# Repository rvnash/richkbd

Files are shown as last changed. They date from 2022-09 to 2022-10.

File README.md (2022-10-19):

# richkbd 2.0
 
The richkbd keyboard is a 42 key single piece Kaihl Choc Hotswap based keyboard which uses the [RP2040](https://www.raspberrypi.com/products/rp2040/) microcontroller. The layout of the keys is identical to two [Corne keyboards](https://github.com/foostan/crkbd) joined together into one. The halves are placed 21° from horizontal and the top keys are separated by 35mm.

If you wanted to construct your own, take a look at the [Build Guide](doc/buildguide.md).

## Features

- Powered by the [RP2040 Stamp](https://www.solder.party/docs/rp2040-stamp) helper board
- USB-C Card edge connector
- Neopixel LED per key
- OLED Display
- Buttons to reset and enter bootloader mode
- Fairly thin with a bottom plate, PCB board layer, and a top layer to hold the sockets
 
## Software

There is a full QMK software implementation which you can find [here](https://github.com/rvnash/qmk_firmware/tree/rvnash_rp2040/keyboards/rvnash/richkbd). If you don't enjoy working from the source, you can find a released flashable version [here](https://github.com/rvnash/qmk_firmware/releases).

## Photos

Here is a completed keyboard with a random selection of keycaps on.

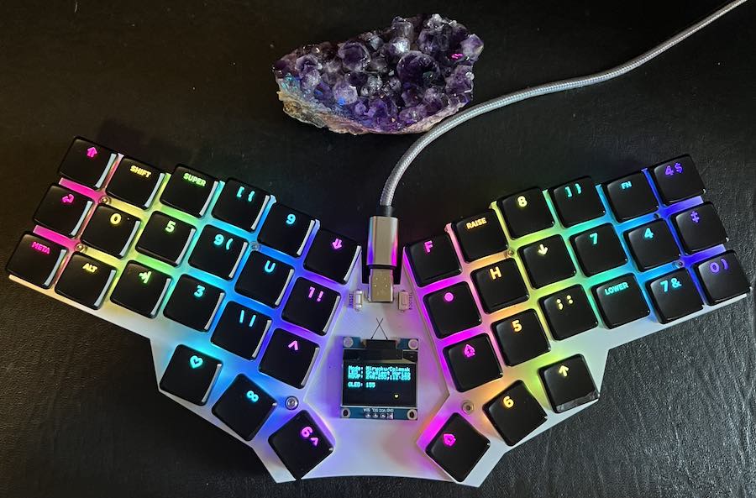
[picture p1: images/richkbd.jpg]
richkbd


Side View

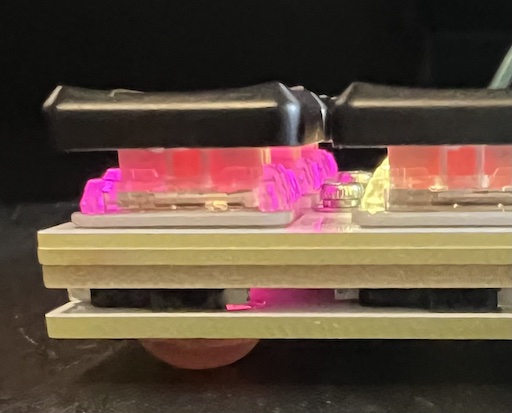
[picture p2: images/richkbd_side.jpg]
richkbd side


The raw PCB

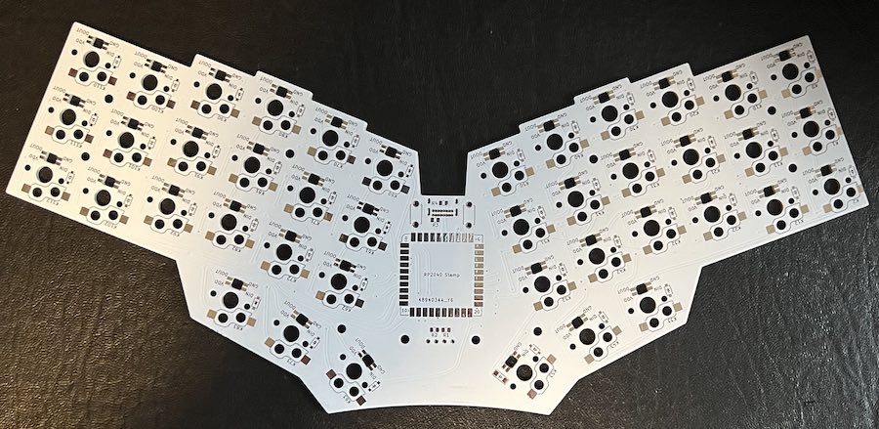
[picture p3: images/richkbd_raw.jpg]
richkbd raw


A soldered PCB

populated

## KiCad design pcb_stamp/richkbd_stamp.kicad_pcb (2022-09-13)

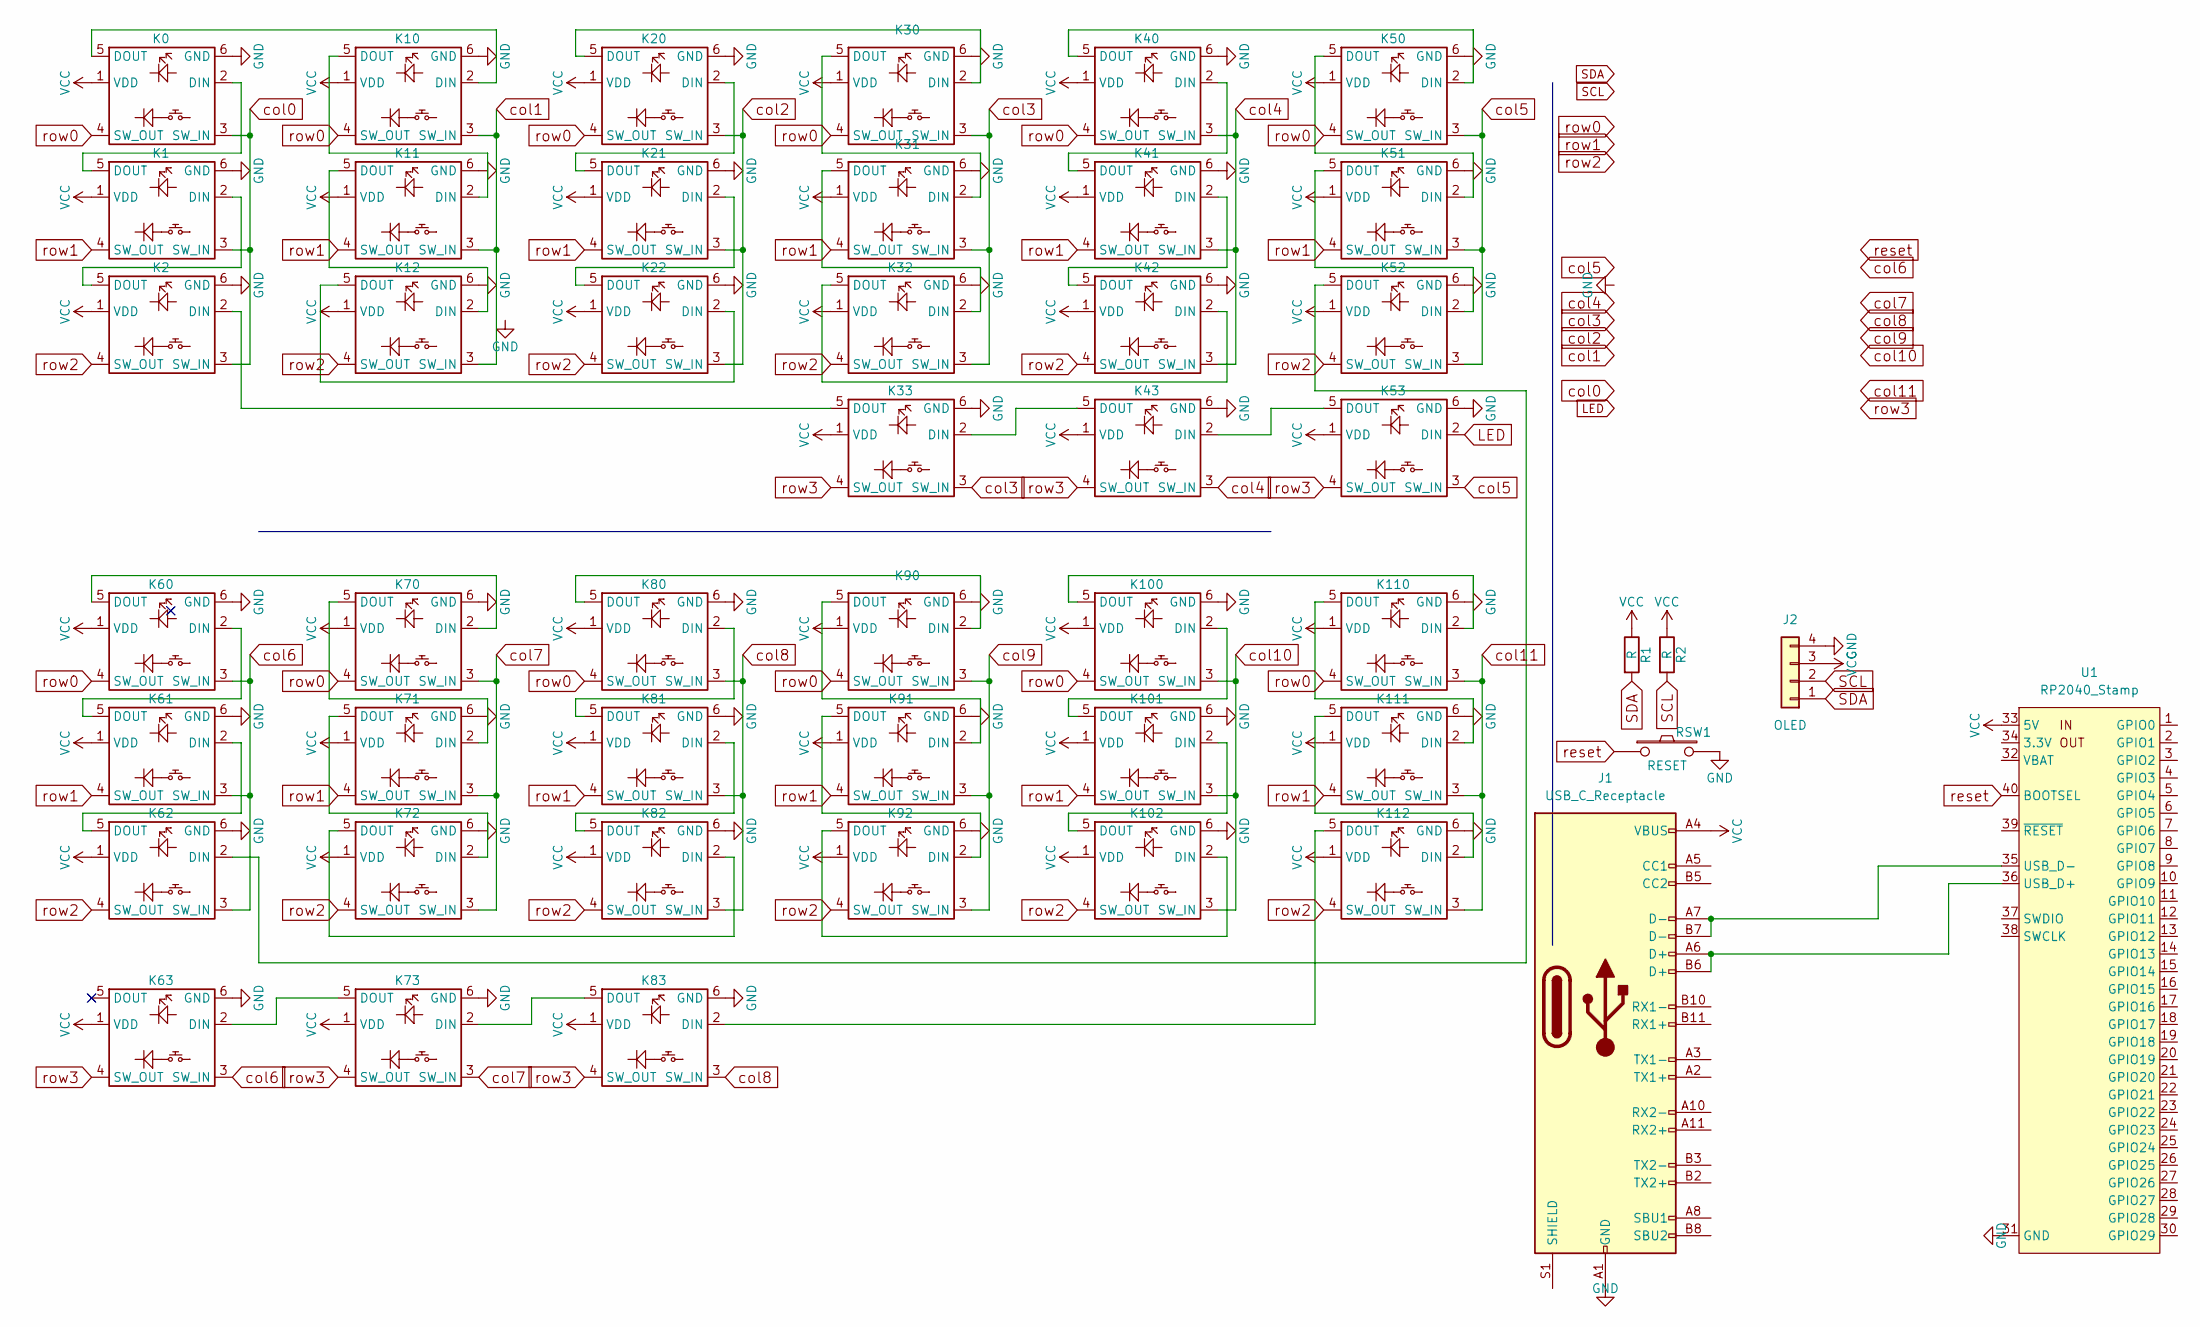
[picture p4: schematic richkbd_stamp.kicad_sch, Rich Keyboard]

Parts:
J1: USB_C_Receptacle
J2: OLED
K0, K1, K2, K10, K11, K12, K20, K21, K22, K30, K31, K32, K33, K40, K41, K42, K43, K50, K51, K52, K53, K60, K61, K62, K63, K70, K71, K72, K73, K80, K81, K82, K83, K90, K91, K92, K100, K101, K102, K110, K111, K112: key-diode-led; key_diode_led
R1, R2: R
RSW1: RESET; ResetSW
U1: RP2040_Stamp; RP2040_Stamp_SMD

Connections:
GND: J1.A1 (GND), J1.A12 (GND), J1.B1 (GND), J1.B12 (GND), J2.4, K0.6 (GND), K1.6 (GND), K2.6 (GND), K10.6 (GND), K11.6 (GND), K12.6 (GND), K20.6 (GND), K21.6 (GND), K22.6 (GND), K30.6 (GND), K31.6 (GND), K32.6 (GND), K33.6 (GND), K40.6 (GND), K41.6 (GND), K42.6 (GND), K43.6 (GND), K50.6 (GND), K51.6 (GND), K52.6 (GND), K53.6 (GND), K60.6 (GND), K61.6 (GND), K62.6 (GND), K63.6 (GND), K70.6 (GND), K71.6 (GND), K72.6 (GND), K73.6 (GND), K80.6 (GND), K81.6 (GND), K82.6 (GND), K83.6 (GND), K90.6 (GND), K91.6 (GND), K92.6 (GND), K100.6 (GND), K101.6 (GND), K102.6 (GND), K110.6 (GND), K111.6 (GND), K112.6 (GND), RSW1.2, U1.31 (GND)
LED: K53.2 (DIN)
unnamed: J1.A6 (D+), J1.B6 (D+), U1.36 (USB_D+)
unnamed: J1.A7 (D-), J1.B7 (D-), U1.35 (USB_D-)
unnamed: K0.2 (DIN), K1.5 (DOUT)
unnamed: K0.5 (DOUT), K10.2 (DIN)
unnamed: K1.2 (DIN), K2.5 (DOUT)
unnamed: K2.2 (DIN), K33.5 (DOUT)
unnamed: K10.5 (DOUT), K11.2 (DIN)
unnamed: K11.5 (DOUT), K12.2 (DIN)
unnamed: K12.5 (DOUT), K22.2 (DIN)
unnamed: K20.2 (DIN), K21.5 (DOUT)
unnamed: K20.5 (DOUT), K30.2 (DIN)
unnamed: K21.2 (DIN), K22.5 (DOUT)
unnamed: K30.5 (DOUT), K31.2 (DIN)
unnamed: K31.5 (DOUT), K32.2 (DIN)
unnamed: K32.5 (DOUT), K42.2 (DIN)
unnamed: K33.2 (DIN), K43.5 (DOUT)
unnamed: K40.2 (DIN), K41.5 (DOUT)
unnamed: K40.5 (DOUT), K50.2 (DIN)
unnamed: K41.2 (DIN), K42.5 (DOUT)
unnamed: K43.2 (DIN), K53.5 (DOUT)
unnamed: K50.5 (DOUT), K51.2 (DIN)
unnamed: K51.5 (DOUT), K52.2 (DIN)
unnamed: K52.5 (DOUT), K62.2 (DIN)
unnamed: K60.2 (DIN), K61.5 (DOUT)
unnamed: K60.5 (DOUT), K70.2 (DIN)
unnamed: K61.2 (DIN), K62.5 (DOUT)
unnamed: K63.2 (DIN), K73.5 (DOUT)
unnamed: K70.5 (DOUT), K71.2 (DIN)
unnamed: K71.5 (DOUT), K72.2 (DIN)
unnamed: K72.5 (DOUT), K82.2 (DIN)
unnamed: K73.2 (DIN), K83.5 (DOUT)
unnamed: K80.2 (DIN), K81.5 (DOUT)
unnamed: K80.5 (DOUT), K90.2 (DIN)
unnamed: K81.2 (DIN), K82.5 (DOUT)
unnamed: K90.5 (DOUT), K91.2 (DIN)
unnamed: K91.5 (DOUT), K92.2 (DIN)
unnamed: K100.2 (DIN), K101.5 (DOUT)
unnamed: K100.5 (DOUT), K110.2 (DIN)
unnamed: K101.2 (DIN), K102.5 (DOUT)
unnamed: K92.5 (DOUT), K102.2 (DIN)
unnamed: K110.5 (DOUT), K111.2 (DIN)
unnamed: K111.5 (DOUT), K112.2 (DIN)
unnamed: K83.2 (DIN), K112.5 (DOUT)
SCL: J2.2, R2.2
SDA: J2.1, R1.2
VCC: J1.A4 (VBUS), J1.A9 (VBUS), J1.B4 (VBUS), J1.B9 (VBUS), J2.3, K0.1 (VDD), K1.1 (VDD), K2.1 (VDD), K10.1 (VDD), K11.1 (VDD), K12.1 (VDD), K20.1 (VDD), K21.1 (VDD), K22.1 (VDD), K30.1 (VDD), K31.1 (VDD), K32.1 (VDD), K33.1 (VDD), K40.1 (VDD), K41.1 (VDD), K42.1 (VDD), K43.1 (VDD), K50.1 (VDD), K51.1 (VDD), K52.1 (VDD), K53.1 (VDD), K60.1 (VDD), K61.1 (VDD), K62.1 (VDD), K63.1 (VDD), K70.1 (VDD), K71.1 (VDD), K72.1 (VDD), K73.1 (VDD), K80.1 (VDD), K81.1 (VDD), K82.1 (VDD), K83.1 (VDD), K90.1 (VDD), K91.1 (VDD), K92.1 (VDD), K100.1 (VDD), K101.1 (VDD), K102.1 (VDD), K110.1 (VDD), K111.1 (VDD), K112.1 (VDD), R1.1, R2.1, U1.33 (5V)
col0: K0.3 (SW_IN), K1.3 (SW_IN), K2.3 (SW_IN)
col1: K10.3 (SW_IN), K11.3 (SW_IN), K12.3 (SW_IN)
col2: K20.3 (SW_IN), K21.3 (SW_IN), K22.3 (SW_IN)
col3: K30.3 (SW_IN), K31.3 (SW_IN), K32.3 (SW_IN), K33.3 (SW_IN)
col4: K40.3 (SW_IN), K41.3 (SW_IN), K42.3 (SW_IN), K43.3 (SW_IN)
col5: K50.3 (SW_IN), K51.3 (SW_IN), K52.3 (SW_IN), K53.3 (SW_IN)
col6: K60.3 (SW_IN), K61.3 (SW_IN), K62.3 (SW_IN), K63.3 (SW_IN)
col7: K70.3 (SW_IN), K71.3 (SW_IN), K72.3 (SW_IN), K73.3 (SW_IN)
col8: K80.3 (SW_IN), K81.3 (SW_IN), K82.3 (SW_IN), K83.3 (SW_IN)
col9: K90.3 (SW_IN), K91.3 (SW_IN), K92.3 (SW_IN)
col10: K100.3 (SW_IN), K101.3 (SW_IN), K102.3 (SW_IN)
col11: K110.3 (SW_IN), K111.3 (SW_IN), K112.3 (SW_IN)
reset: RSW1.1, U1.40 (BOOTSEL)
row0: K0.4 (SW_OUT), K10.4 (SW_OUT), K20.4 (SW_OUT), K30.4 (SW_OUT), K40.4 (SW_OUT), K50.4 (SW_OUT), K60.4 (SW_OUT), K70.4 (SW_OUT), K80.4 (SW_OUT), K90.4 (SW_OUT), K100.4 (SW_OUT), K110.4 (SW_OUT)
row1: K1.4 (SW_OUT), K11.4 (SW_OUT), K21.4 (SW_OUT), K31.4 (SW_OUT), K41.4 (SW_OUT), K51.4 (SW_OUT), K61.4 (SW_OUT), K71.4 (SW_OUT), K81.4 (SW_OUT), K91.4 (SW_OUT), K101.4 (SW_OUT), K111.4 (SW_OUT)
row2: K2.4 (SW_OUT), K12.4 (SW_OUT), K22.4 (SW_OUT), K32.4 (SW_OUT), K42.4 (SW_OUT), K52.4 (SW_OUT), K62.4 (SW_OUT), K72.4 (SW_OUT), K82.4 (SW_OUT), K92.4 (SW_OUT), K102.4 (SW_OUT), K112.4 (SW_OUT)
row3: K33.4 (SW_OUT), K43.4 (SW_OUT), K53.4 (SW_OUT), K63.4 (SW_OUT), K73.4 (SW_OUT), K83.4 (SW_OUT)

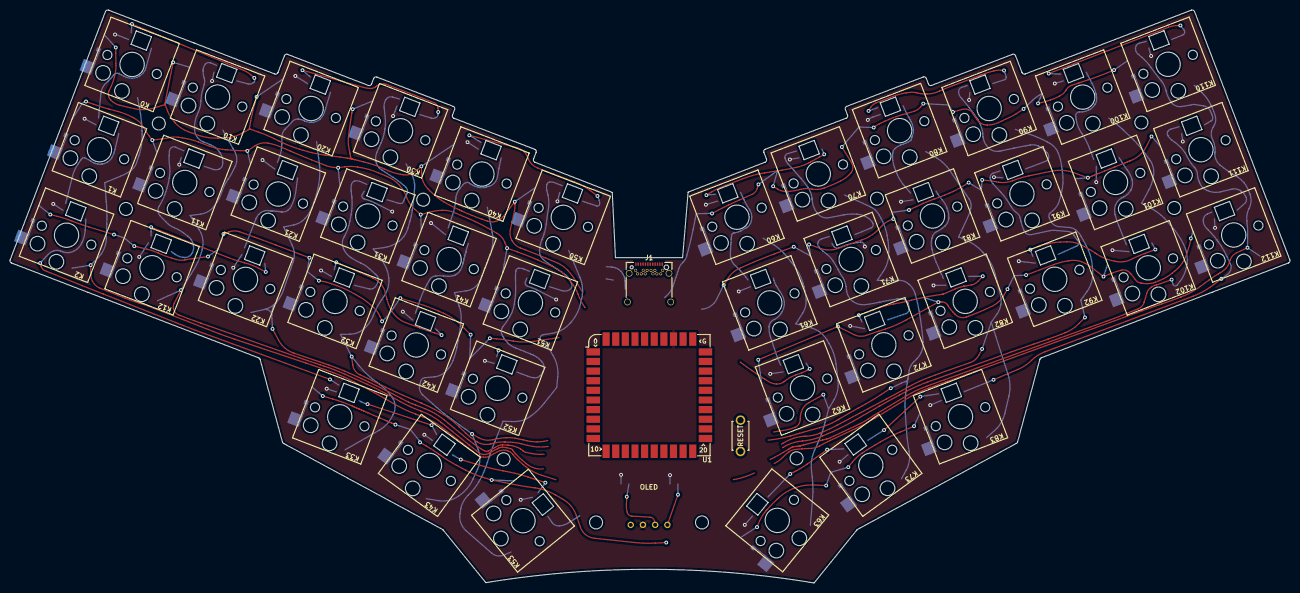
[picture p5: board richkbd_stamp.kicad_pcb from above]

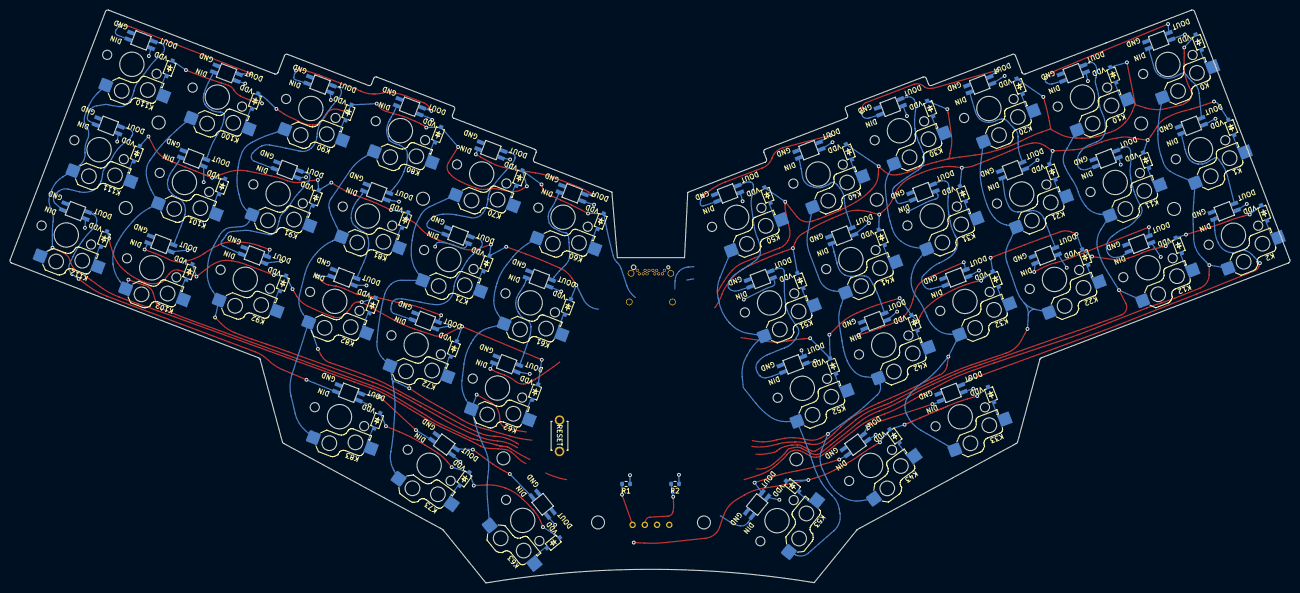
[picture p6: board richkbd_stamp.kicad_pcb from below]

Board: 2 copper layers, 265.9 x 119.0 mm, 48 parts (2 on the bottom side), 64 nets.

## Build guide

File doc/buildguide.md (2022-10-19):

# Build Guide

## Part List
These parts are needed to create a complete keyboard. The "where to get it" column are just suggestions. There are many places to source most all of these parts.tt

| Count | Part | Description | Where to get it |
| --- | --- | --- | --- |
| 1  | PCB | The printed circuit board onto which will be mounted all of the components. | Here is the [Gerber File](../pcb_stamp/production/gerber.zip) to send to have the board fabricated. I used JLCPCB, and got excellent results for a good price. |
| 4 | Top Plate | The non-electrical plates that mechanically serve to hold the Choc switches in place. Two are required on each side. | [Gerber File](../top_plate/production/gerber.zip) **Note that these boards can be either 1mm or 2mm in thickness. The 2mm boards are much more expensive to fabricate, so take two 1mm boards and stack them.** |
| 1 | Bottom Plate | The non-electrical plate that serves as the base of the keyboard | [Gerber File](../bottom_plate/production/gerber.zip) |
| 42 | Choc sockets | Hotswappable Choc Sockets | [Adafruit Link](https://www.adafruit.com/product/5118)  |
| 42 | Choc switches | Pick your favorite switches | [Kailh](http://www.kailh.com/en/Products/Ks/CS/) |
| 42 | Keycaps | Choc compatible keycaps | [Little Keyboards Link](https://www.littlekeyboards.com/products/mbk-40s-keycaps) |
| 43 | Diodes | Vishay 1N4148W-E3-18 (Note there are **43** of these) | [Digi-Key Link](https://www.digikey.com/en/products/detail/vishay-general-semiconductor-diodes-division/1N4148W-E3-18/3104163) |
| 42 | LEDS | Neopixel Reverse Mount RGB LEDs (SK6812-E) | [Adafruit Link](https://www.adafruit.com/product/4960) |
| 2 | 10K SMD Resistors | Stackpole RMCF0603JT10K0 | [Digi-Key Link](https://www.digikey.com/en/products/detail/stackpole-electronics-inc/RMCF0603JT10K0/1758104) |
| 2 | 5.1K SMD Resistors | Stackpole RMCF0603FT5K10 | [Digi-Key Link](https://www.digikey.com/en/products/detail/stackpole-electronics-inc/RMCF0603FT5K10/1760908) |
| 1 | RP2040 Stamp | RP2040 based MCU board | [Tindie Link](https://www.tindie.com/products/arturo182/rp2040-stamp/) |
| 1 | 128x64 Display | I2C OLED Display Module | [Amazon Link](https://www.amazon.com/dp/B0B7RPCZ4Z?psc=1&ref=ppx_yo2ov_dt_b_product_details) |
| 1 | USB-C Connector | GCT USB4085-GF-A | [Digi-Key Link](https://www.digikey.com/en/products/detail/gct/USB4085-GF-A/9859662) |
| 2 | Push buttons | For reset and boot-select | [Adafruit Link](https://www.adafruit.com/product/1489) |
| 8 | M2*10 Screws | To hold the layers together | Assortment Kit at [Amazon](https://www.amazon.com/dp/B082XRX17Z?psc=1&ref=ppx_yo2ov_dt_b_product_details) |
| 8 | M2 Nuts | | See kit above |
| 16 | M2 Washers | | See kit above |
| 8 | Rubber Feet | | [Amazon Link](https://www.amazon.com/Adhesive-Drawers-Furniture-Dampening-Transparent/dp/B08NX9KXQP) |

## Steps

### 1. Soldering the LEDS, Diodes, and Resistors

I listed this as one step, because I use a reflow oven to solder them all at once. These parts are large enough, however, to solder them by hand. Just use a narrow tipped soldering iron.

#### A. LEDS

I'm told that the Neopixel LEDS are liable to be damaged by excessive heat. So turn down your iron, and pause between pads to let the heat disipate. Also, these may just barely fit in the holes, so you may need to push them in a bit. Finally, place them with the LED side facing away from the component side. This is the "up" direction when the keyboard is complete. And orient the leads so that the one with the *clipped corner* is the GND lead. This is a little difficult to see in the photo below, so take a look at the [datasheet](https://cdn-shop.adafruit.com/product-files/4960/4960_SK6812MINI-E_REV02_EN.pdf) to see a line drawing.

Picture of LED w/ ground marked

Because the LEDs all communicate serially, if there is a failure of one, it will take out all of the following LEDS in the chain. See the picture for the order in which the LEDs are connected, 1 through 42.

Picture of board w/ numbers on the LEDs

If you have a failure, find the first LED that is not working. The problem is most likely in that LED, or the one just preceding it in the chain. Check carefully your soldering. You can check the continuity, for example, between DOUT of one LED and DIN of the next. Or you can check the VDD or GND connections. If you can't find the problem, then replace the suspicious LEDs.

#### B. Diodes

There are 43 diodes, one for each switch, and one additional. Solder the diodes in the orientation shown, with the (very) faint line on the diode facing the same way as the diode symbol points.

Picture of a single diode

#### C. Resistors

There are 4 surface mount resistors, two near the USB-C connector, and two near the OLED display connections. Orientation does not matter. Just make sure you put the 5.1K resistor near the USB-C connector (R4 and R5), and the 10K resistors near the OLED display (R1 and R2).

Picture of resistors

### 2. The Sockets

The sockets not only require an electrical connection, but a good physical one too. This is because there is some force on the socket when inserting switches. Don't be afraid to use a good bit of solder, however, be cautious that the solder doesn't run inside the socket and foul the hot-swappable springs that hold the switches.

Picture closeup of sockets

### 3. The RP2040 Stamp

Use an Exacto knife to cut the center of these jumpers to disable the Neopixel on the Stamp itself doesn't light up.

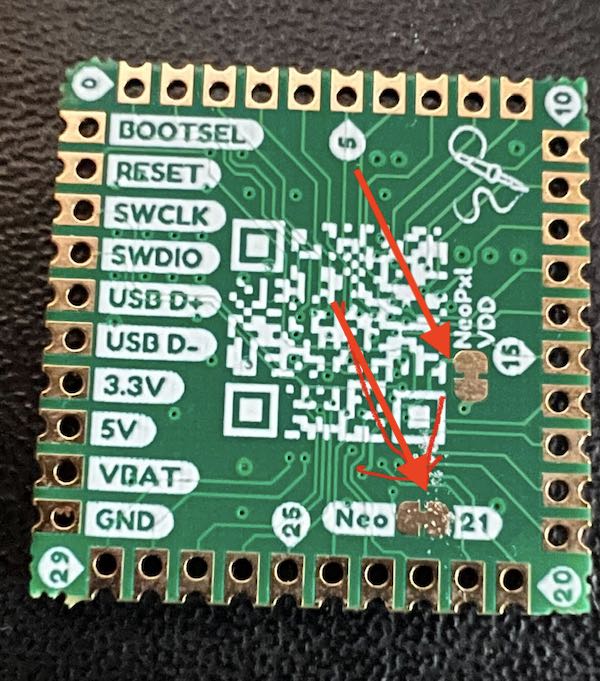
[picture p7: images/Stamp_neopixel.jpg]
stamp_neo


Carefully position the Stamp in the correct orientation, and lined up around all 4 sides. Tack down the daughter board with one or two castelated pads to the pad on the PCB. Once you have that done, it should be quick work to solder the rest of the pads all around.

Picture closeup of stamp soldered in

### 4. The USB-C Connector (top side)

This can be hard to get right. The way I did it is to put a bit of solder paste on the pins of the socket, insert it into the holes, and then soldering the strain relief around the shield down. Then I heated each through-hole with the iron, and that seemed to work to attach the pins. I'm not too happy with this method, because I can't see how good of a job inside the holes, but it works. 🤷

Picture closeup of USB-C

### 5. The Push Buttons (top side)

These are easy. Just stick them through the holes and solder.

### 6. The OLED Display (top side)

I removed the plastic spacer from the pins and just soldered it as flat as I could against the top of the PCB.

Picture of edge of oled

### 7. Testing

Before you screw the whole thing together, I would suggest some tests to see if it all works.

1. Connect the keyboard's raw soldered PCB to a computer. The unprogammed RP2040 should mount as a flash drive in your OS. Download the `rvnash_richkbd_default.uf2` file from the [latest release](https://github.com/rvnash/qmk_firmware/releases) and drag it into that flash drive. The RP2040 should restart, and connect itself as a keyboard to the system. The LEDS should also light up.
2. You can use a pair of tweezers to make contact accross a few sockets and test that some characters show on the screen.
3. You could put switches in every socket, and see that they all work.
4. The OLED display should have status on it.

### 8. Final assembly

If everything seems to work, just screw it all together with a washer on the top and bottom. From the bottom to the top, these are the layers to stack.

1. Bottom plate
2. PCB (fully populated)
3. 2 x Top plates per side (for a total of 4). These should be double stacked on each side.
4. The switches
5. The keycaps

Put a few rubber bumpers on the bottom so the screws aren't on the desk.

Good luck, have fun and reach out with any questions.

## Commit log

2022-09-01 Initialize with very incomplete schematic
    [richkbd.kicad_pcb, richkbd.kicad_sch]
2022-09-01 Completed 2 columns of switches and improved symmetry
    [richkbd.kicad_sch]
2022-09-01 Completed schematic, but need to decide on rp2040 or not
    [richkbd.kicad_sch]
2022-09-02 Start of board layout
    [richkbd.kicad_pcb, richkbd.kicad_sch]
2022-09-03 switches laid
    [richkbd.kicad_pcb]
2022-09-12 Left side routed
    [richkbd.kicad_sch]
2022-09-12 Added a few more traces
2022-09-13 Finished routing and added start at stamp version
    [richkbd_stamp.kicad_pcb, richkbd_stamp.kicad_sch]
2022-09-15 Finished stamp routing
    [richkbd_stamp.kicad_sch]
2022-09-15 Moved OLED up and fixed pin orientation
    [richkbd_stamp.kicad_sch]
2022-09-15 Sent off for fab at JLC PCB
    [richkbd.kicad_sch, richkbd_bottom_plate.kicad_pcb, richkbd_bottom_plate.kicad_sch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]
2022-09-18 Connected row3
    [richkbd_stamp.kicad_sch]
2022-09-19 Start of rev2
    Moved stamp to back
    [richkbd_stamp.kicad_sch]
2022-09-20 Put stamp on the bottom layer
    [richkbd_top_plate.kicad_pcb]
2022-09-27 New layout for update to footprint of the neopixen
2022-09-28 Added diode on first LED pixel power pin to bring it into spec for the rp2040's 3.3V logic
    [richkbd_stamp.kicad_sch]
2022-09-28 Changed the diode footprint for first one
2022-09-28 Minor tweaks.
    [richkbd_stamp.kicad_sch]
2022-09-29 Clean up some traces.
2022-10-15 Updated resistor values and moved lightsabres
    [richkbd_stamp.kicad_sch]
2022-10-18 A good start at the documentation.
    [richkbd_bottom_plate.kicad_pcb, richkbd_top_plate.kicad_pcb]
2022-10-18 Fix links to gerber files
2022-10-22 Made LED holes slightly larger
